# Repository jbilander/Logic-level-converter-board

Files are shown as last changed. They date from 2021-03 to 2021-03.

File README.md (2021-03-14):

# Logic-level-converter-board
A bi-directional high-speed TTL-Compatible level shifter board 5V ⇄ 3V3 for tinkering

***

<a href="images/screenshot_pic1.png">
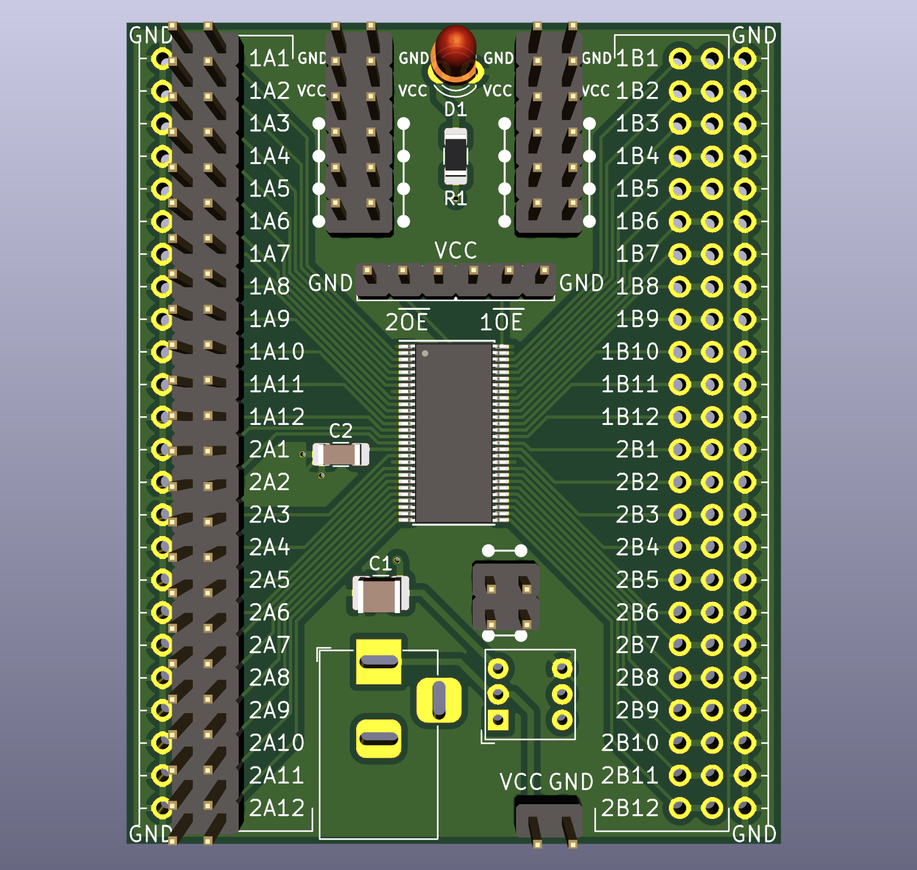
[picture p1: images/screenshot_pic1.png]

</a>
<a href="images/screenshot_pic2.png">
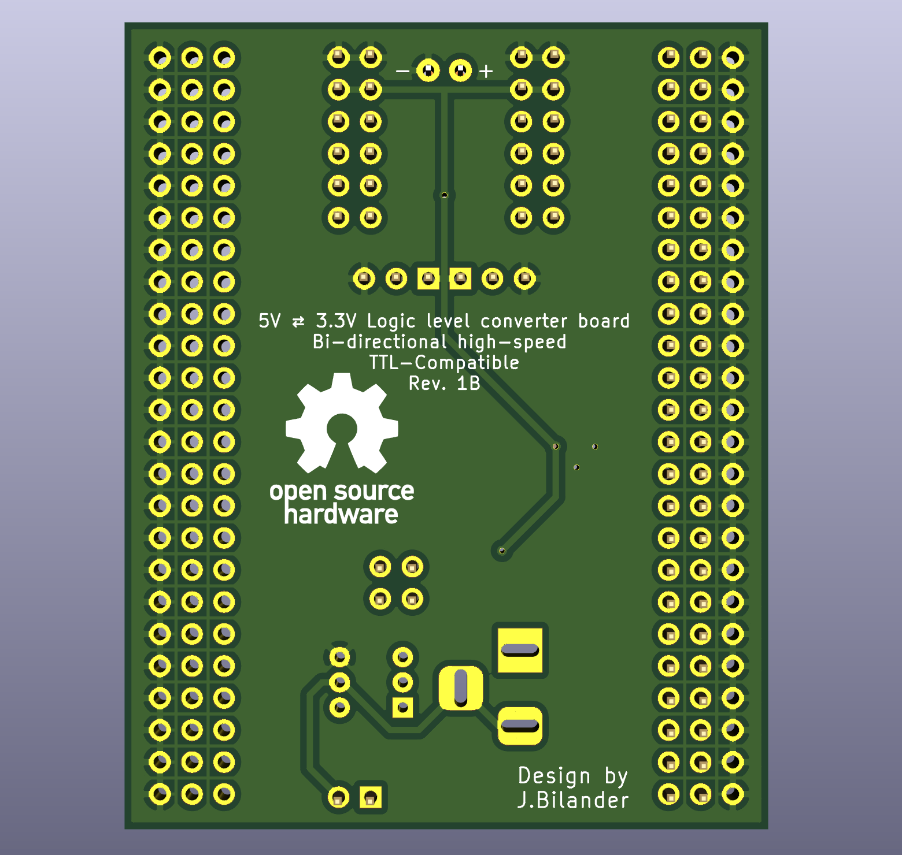
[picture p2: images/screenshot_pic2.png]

</a>
<a href="images/SW_7x7x12mm_DPDT.jpg">
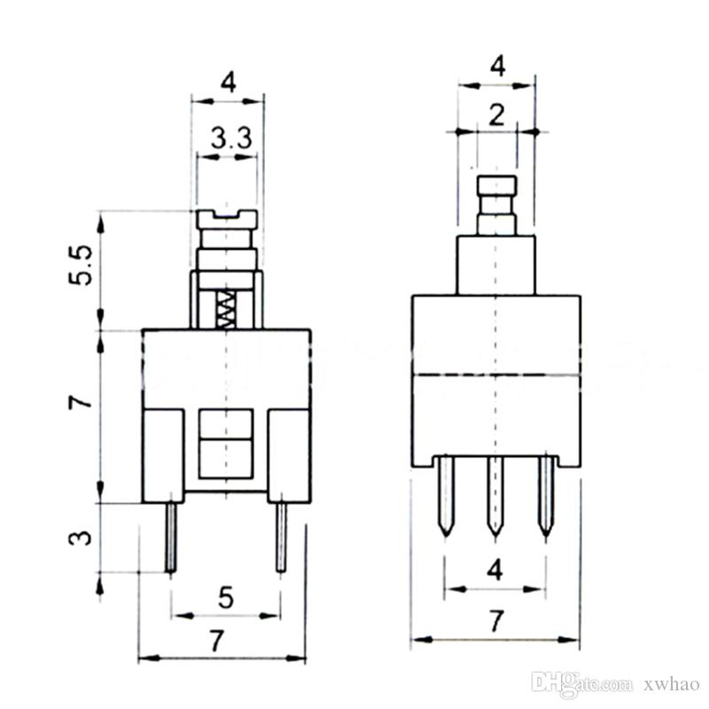
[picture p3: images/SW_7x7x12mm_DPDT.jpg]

</a>
<a href="images/pushbutton_sw.jpg">
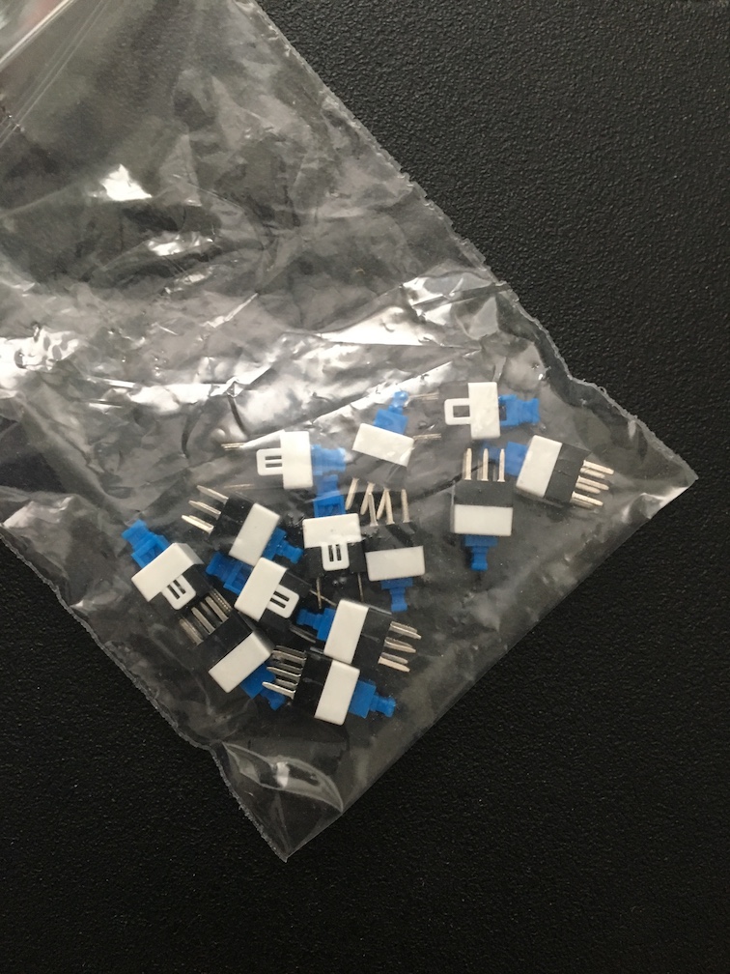
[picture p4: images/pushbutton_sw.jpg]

</a>
<a href="images/barrel_jack_connector.jpg">
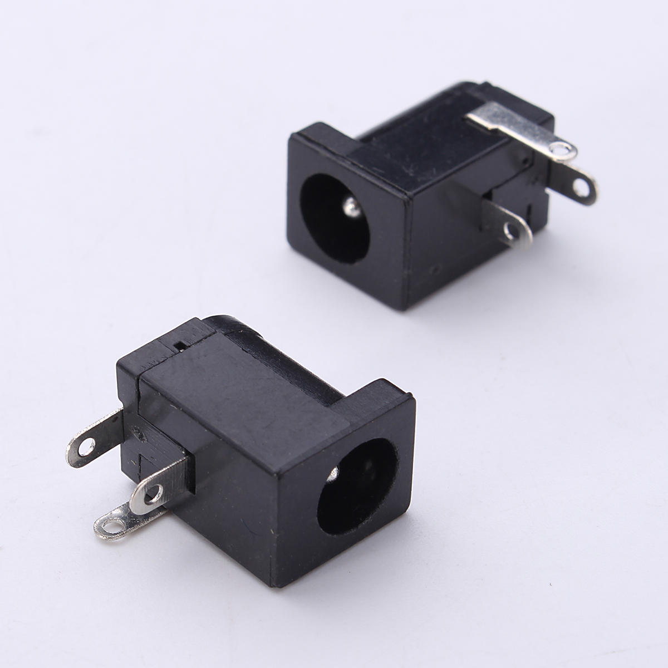
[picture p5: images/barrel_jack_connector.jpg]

</a>
<a href="images/board_build_complete.jpg">
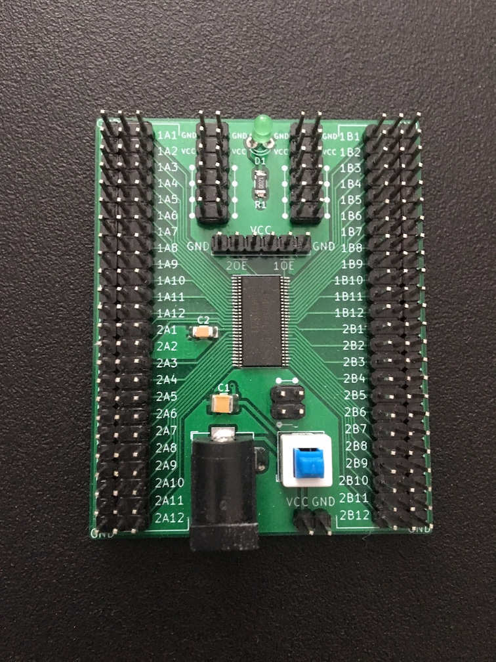
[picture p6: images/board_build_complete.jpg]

</a>

PART  | Value       | Description
---| ---------------| -------
D1 | 2.54 mm pin pitch | LED Diode (optional Power on/off indicator)
R1 | 100-330 Ohm | 1206 (populate if D1, calculate suitable resistor value to use with D1)
C1 | 10-100 uF   | 1210
C2 | 0.1 uF      | 1206
U1 | SN74CBTD16211 https://www.ti.com/lit/ds/symlink/sn74cbtd16211.pdf| TSSOP-56_6.1x14mm_P0.5mm
 | Pushbutton switch SW_7x7x12mm_DPDT
 | Barrel Jack 5.5x2.1mm
 | Power +5V center pin positive or via pinheader (verify polarity before connecting)
 | 2.54 mm jumpers to enable/disable /1OE (first 12-bits) and /2OE (second 12-bits), either enable via jumper to GND or disable via VCC.
 | 2.54 mm jumpers to disable unused inputs via jumper to GND.
 | A lot of 2.54mm pinheader strips. 

Happy Tinkerin'

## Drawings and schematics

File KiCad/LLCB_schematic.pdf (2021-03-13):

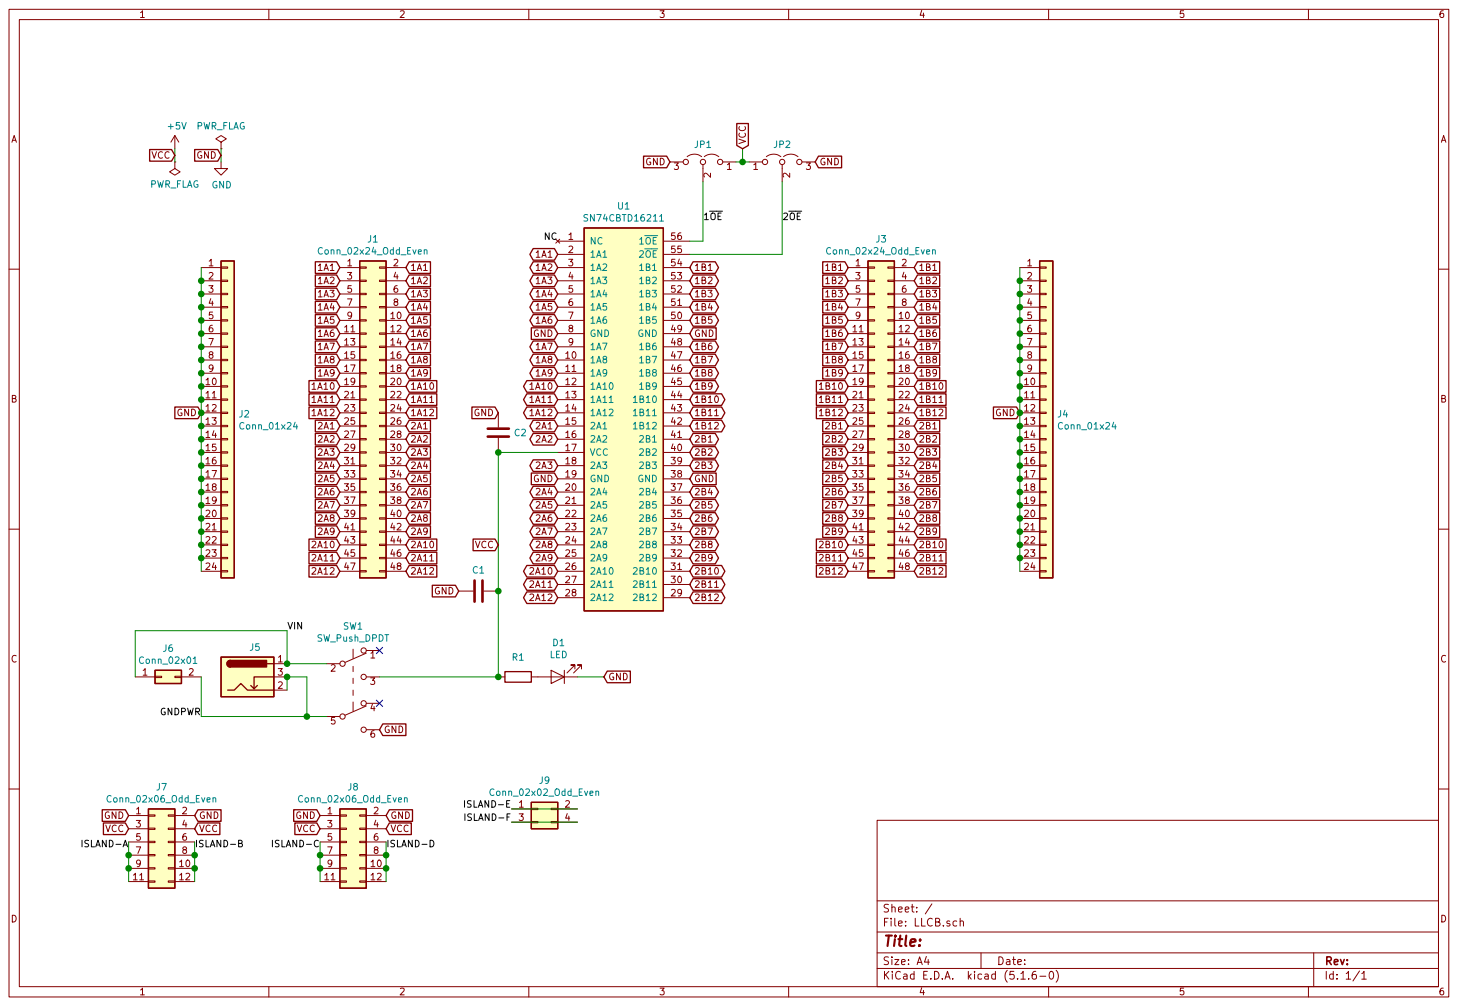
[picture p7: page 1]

Id: 1/1 Title: File: LLCB.sch Sheet: /

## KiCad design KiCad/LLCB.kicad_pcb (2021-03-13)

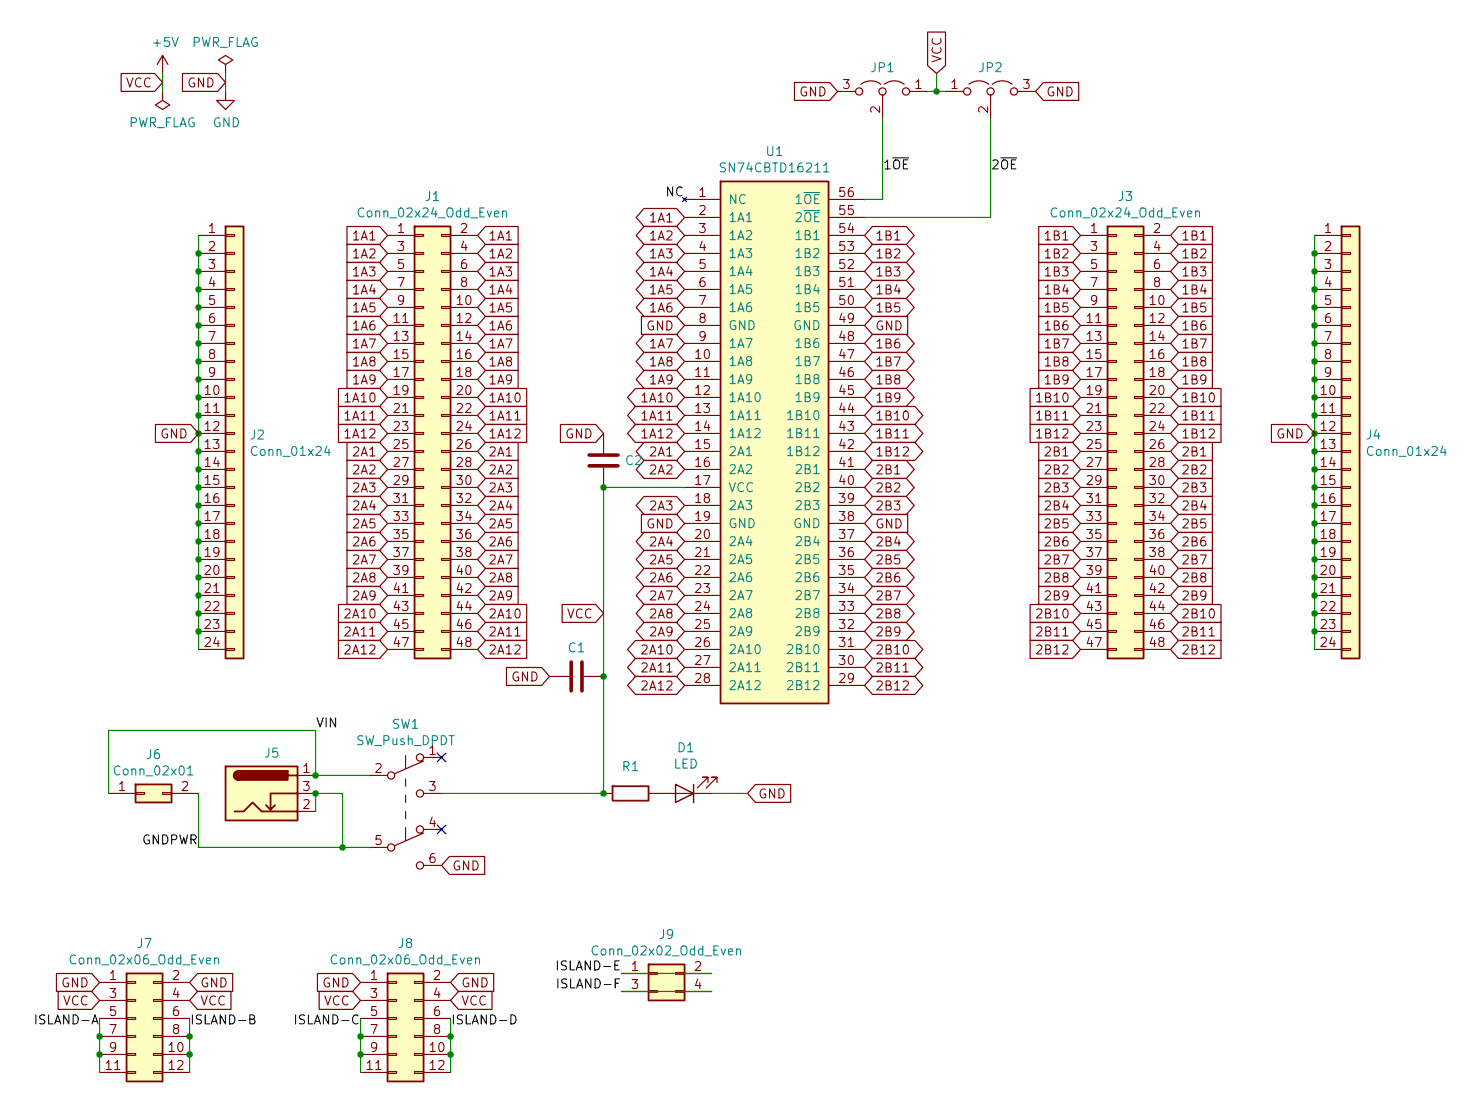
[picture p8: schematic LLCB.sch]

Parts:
C1: C; C_1210_3225Metric_Pad1.42x2.65mm_HandSolder
C2: C; C_1206_3216Metric_Pad1.42x1.75mm_HandSolder
D1: LED; LED_D3.0mm
J1, J3: Conn_02x24_Odd_Even; PinHeader_2x24_P2.54mm_Vertical
J2, J4: Conn_01x24; PinHeader_1x24_P2.54mm_Vertical
J5: Barrel_Jack_Switch; BarrelJack_Horizontal
J6: Conn_02x01; PinHeader_2x01_P2.54mm_Vertical
J7, J8: Conn_02x06_Odd_Even; PinHeader_2x06_P2.54mm_Vertical
J9: Conn_02x02_Odd_Even; PinHeader_2x02_P2.54mm_Vertical
JP1, JP2: Jumper_3_Open; PinHeader_1x03_P2.54mm_Vertical
R1: R; R_1206_3216Metric_Pad1.42x1.75mm_HandSolder
SW1: SW_Push_DPDT; SW_Push_THT_7x7x12mm_DPDT
U1: SN74CBTD16211; TSSOP-56_6.1x14mm_P0.5mm

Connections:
1A1: J1.1, J1.2, U1.2 (1A1)
1A2: J1.3, J1.4, U1.3 (1A2)
1A3: J1.5, J1.6, U1.4 (1A3)
1A4: J1.7, J1.8, U1.5 (1A4)
1A5: J1.9, J1.10, U1.6 (1A5)
1A6: J1.11, J1.12, U1.7 (1A6)
1A7: J1.13, J1.14, U1.9 (1A7)
1A8: J1.15, J1.16, U1.10 (1A8)
1A9: J1.17, J1.18, U1.11 (1A9)
1A10: J1.19, J1.20, U1.12 (1A10)
1A11: J1.21, J1.22, U1.13 (1A11)
1A12: J1.23, J1.24, U1.14 (1A12)
1B1: J3.1, J3.2, U1.54 (1B1)
1B2: J3.3, J3.4, U1.53 (1B2)
1B3: J3.5, J3.6, U1.52 (1B3)
1B4: J3.7, J3.8, U1.51 (1B4)
1B5: J3.9, J3.10, U1.50 (1B5)
1B6: J3.11, J3.12, U1.48 (1B6)
1B7: J3.13, J3.14, U1.47 (1B7)
1B8: J3.15, J3.16, U1.46 (1B8)
1B9: J3.17, J3.18, U1.45 (1B9)
1B10: J3.19, J3.20, U1.44 (1B10)
1B11: J3.21, J3.22, U1.43 (1B11)
1B12: J3.23, J3.24, U1.42 (1B12)
2A1: J1.25, J1.26, U1.15 (2A1)
2A2: J1.27, J1.28, U1.16 (2A2)
2A3: J1.29, J1.30, U1.18 (2A3)
2A4: J1.31, J1.32, U1.20 (2A4)
2A5: J1.33, J1.34, U1.21 (2A5)
2A6: J1.35, J1.36, U1.22 (2A6)
2A7: J1.37, J1.38, U1.23 (2A7)
2A8: J1.39, J1.40, U1.24 (2A8)
2A9: J1.41, J1.42, U1.25 (2A9)
2A10: J1.43, J1.44, U1.26 (2A10)
2A11: J1.45, J1.46, U1.27 (2A11)
2A12: J1.47, J1.48, U1.28 (2A12)
2B1: J3.25, J3.26, U1.41 (2B1)
2B2: J3.27, J3.28, U1.40 (2B2)
2B3: J3.29, J3.30, U1.39 (2B3)
2B4: J3.31, J3.32, U1.37 (2B4)
2B5: J3.33, J3.34, U1.36 (2B5)
2B6: J3.35, J3.36, U1.35 (2B6)
2B7: J3.37, J3.38, U1.34 (2B7)
2B8: J3.39, J3.40, U1.33 (2B8)
2B9: J3.41, J3.42, U1.32 (2B9)
2B10: J3.43, J3.44, U1.31 (2B10)
2B11: J3.45, J3.46, U1.30 (2B11)
2B12: J3.47, J3.48, U1.29 (2B12)
/1~OE: JP1.2 (C), U1.56 (1~OE)
/2~OE: JP2.2 (C), U1.55 (2~OE)
/ISLAND-A: J7.5, J7.7, J7.9, J7.11
/ISLAND-B: J7.6, J7.8, J7.10, J7.12
/ISLAND-C: J8.5, J8.7, J8.9, J8.11
/ISLAND-D: J8.6, J8.8, J8.10, J8.12
/ISLAND-E: J9.1, J9.2
/ISLAND-F: J9.3, J9.4
/NC: U1.1 (NC)
GND: C1.2, C2.1, D1.1 (K), J2.1, J2.2, J2.3, J2.4, J2.5, J2.6, J2.7, J2.8, J2.9, J2.10, J2.11, J2.12, J2.13, J2.14, J2.15, J2.16, J2.17, J2.18, J2.19, J2.20, J2.21, J2.22, J2.23, J2.24, J4.1, J4.2, J4.3, J4.4, J4.5, J4.6, J4.7, J4.8, J4.9, J4.10, J4.11, J4.12, J4.13, J4.14, J4.15, J4.16, J4.17, J4.18, J4.19, J4.20, J4.21, J4.22, J4.23, J4.24, J7.1, J7.2, J8.1, J8.2, JP1.3 (B), JP2.3 (B), SW1.6 (C), U1.8 (GND), U1.19 (GND), U1.38 (GND), U1.49 (GND)
GNDPWR: J5.2, J5.3, J6.2, SW1.5 (B)
unnamed: D1.2 (A), R1.1
VCC: C1.1, C2.2, J7.3, J7.4, J8.3, J8.4, JP1.1 (A), JP2.1 (A), R1.2, SW1.3 (C), U1.17 (VCC)
VIN: J5.1, J6.1, SW1.2 (B)

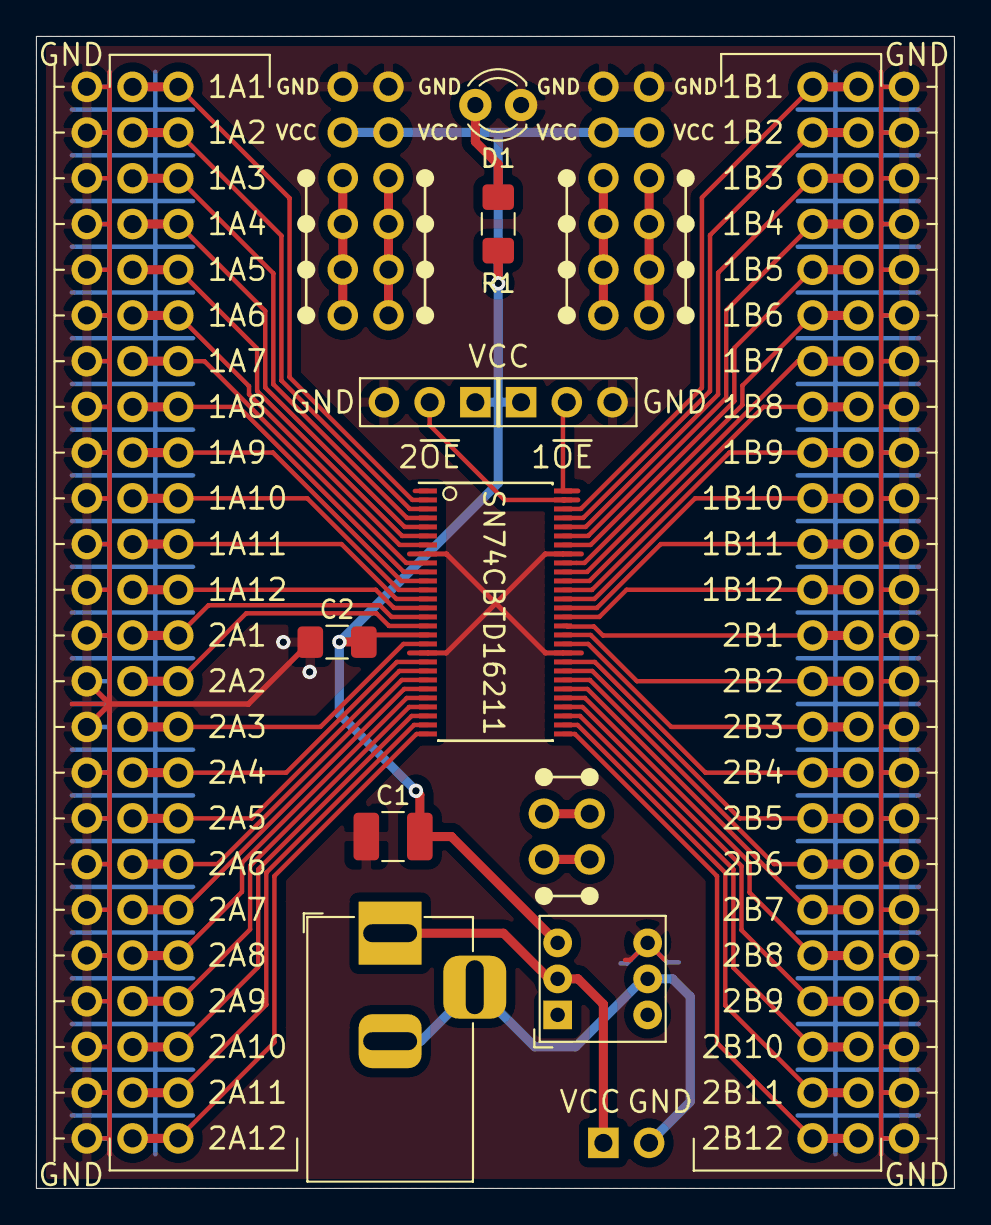
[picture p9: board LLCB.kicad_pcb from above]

Board: 2 copper layers, 51.0 x 64.0 mm, 17 parts (0 on the bottom side), 61 nets.
